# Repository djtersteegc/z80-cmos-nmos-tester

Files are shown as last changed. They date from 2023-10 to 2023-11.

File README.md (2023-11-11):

Test your Z80 CPU at multiple frequencies and detemine if your remarked chip from China is a NMOS or CMOS variant. Based  on the work originally by [Виталий Рудик](https://oshwlab.com/vitalian1980/z80-tester) and later respun/improved by [kinzi](https://www.forum64.de/index.php?thread/133402-z80-tester-zum-testen-unbekannter-z80-cpus/).

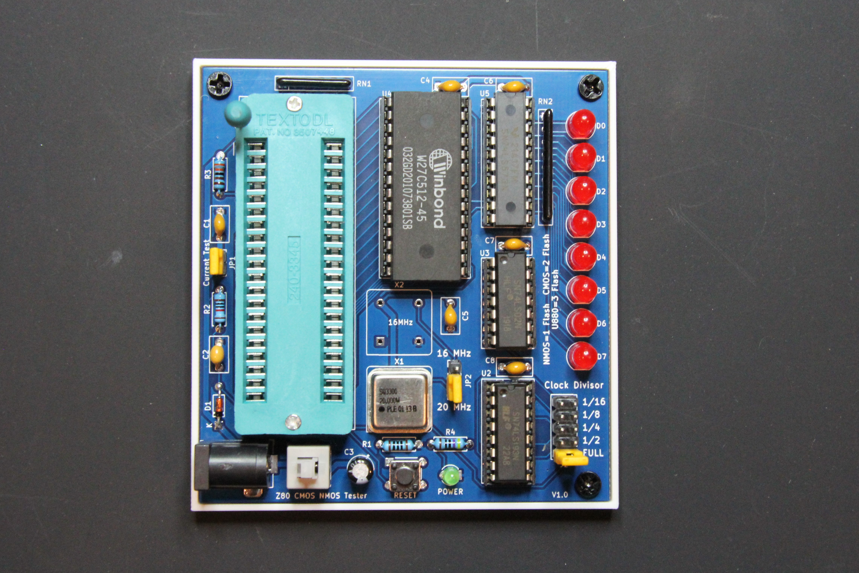
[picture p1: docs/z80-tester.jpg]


I respun the PCB again to add a few quality of life improvements I wanted like a barrel power connetor, power switch and  LED, current measuring header, improved reset circuitry, and switched to 1/2 can oscillators instead of using a crystal and associated components (Pierce oscillator).

Unlike a simple NOP tester, this one works by loading a simple program from the EPROM/EEPROM.  It first checks the variant by using undocumented instructions like `OUT (C),0` , flashes the LED array one to three times to indicate the type, and then does a LED chaser display up and down the various data bus lines. Takes up to two 1/2 can oscillators and with the frequency dividers can test at the following frequencies. 

| Divider | 20 MHz Oscillator | 16 MHz Oscillator |
| --- | --- | --- |
| Full | 20 MHz | 16 MHz |
| 1/2 | 10 MHz | 8 MHz |
| 1/4 | 5 MHz | 4 MHz |
| 1/8 | 2.5 MHz | 2 MHz |
| 1/16 | 1.25 MHz | 1 MHz |

### BOM

There is an interactive BOM [here](https://djtersteegc.github.io/z80-cmos-nmos-tester/ibom.html) or [CSV](https://djtersteegc.github.io/z80-cmos-nmos-tester/z80-cmos-nmos-tester-BOM.csv).  I like using Winbond W27C512 EEPROM's in 27C512 applications since they don't require UV to erase like a traditional EPROM.

### Assembly

In the 3D directory there are STL's to print an (optional) LED alignment jig, some support blocks to keep the board level while you solder the LED's, and a simple mounting plate. Secure the PCB to the plate with M3 x 4mm screws.

### Firmware Programming

kinzi's rev3 firmare can be found in the zip file in the **firmware** directory.  Burn **test.z80.u880.rev3.bin** to a 27C512 compatible EPROM/EEPROM.

### Usage

Supply 5V center positive to the 5.5mm x 2.1mm DC power jack. On power up, the Z80 should automatically reset, if not, push the reset button.  The LED array will flash once for NMOS variants, twice for CMOS, or three times for a U880.  After that, the LED's will go "knight rider", and then reset in a continous loop.  Use the two jumpers to select the appropiate osciallator and frequency divider you want to test at.

JP1 (Current Test) feeds 5V to the Z80. Remove the jumper and attached a multimeter in current mode if you would like to test current draw of your Z80, another way to tell NMOS and CMOS variants apart. NMOS is around 200mA, CMOS is between 10 to 100mA depending on clock frequency.

Here's a quick demo of the board in action with both a real and fake 20MHz CMOS version from a batch of ten from AliExpress, https://youtu.be/2GuPsmFTtck

https://youtu.be/2GuPsmFTtck

### Getting a PCB Board

Any extras I have available will be in my [Tindie](https://www.tindie.com/products/tersteeg/z80-cmos-nmos-tester-pcb/) store. I don't ship outside the US currently, but gerber files are available if you want to order your own from your favorite PCB fab like JLCPCB or PCBWay.

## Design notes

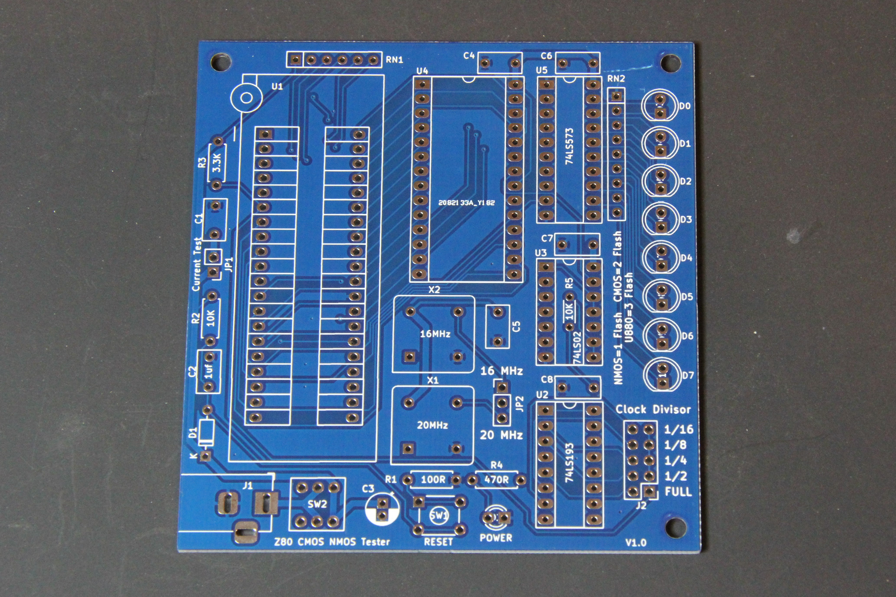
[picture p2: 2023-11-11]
docs/pcb.jpg

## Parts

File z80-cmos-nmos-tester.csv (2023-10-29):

# | Reference | Qty | Value | Footprint | DNP
1 | C1, C4, C5, C6, C7, C8 | 6 | 100nf | Capacitor_THT:C_Rect_L7.0mm_W3.5mm_P5.00mm
2 | C2 | 1 | 1uf | Capacitor_THT:C_Rect_L7.0mm_W3.5mm_P5.00mm
3 | C3 | 1 | 100uf | Capacitor_THT:CP_Radial_D5.0mm_P2.00mm
4 | D1 | 1 | BAT42 | Diode_THT:D_DO-35_SOD27_P7.62mm_Horizontal
5 | D2 | 1 | POWER | LED_THT:LED_D3.0mm
6 | D3 | 1 | D0 | LED_THT:LED_D5.0mm
7 | D4 | 1 | D1 | LED_THT:LED_D5.0mm
8 | D5 | 1 | D2 | LED_THT:LED_D5.0mm
9 | D6 | 1 | D3 | LED_THT:LED_D5.0mm
10 | D7 | 1 | D4 | LED_THT:LED_D5.0mm
11 | D8 | 1 | D5 | LED_THT:LED_D5.0mm
12 | D9 | 1 | D6 | LED_THT:LED_D5.0mm
13 | D10 | 1 | D7 | LED_THT:LED_D5.0mm
14 | H1, H2, H3 | 3 | MountingHole | MountingHole:MountingHole_3.2mm_M3
15 | J1 | 1 | Barrel_Jack | Connector_BarrelJack:BarrelJack_Horizontal
16 | J2 | 1 | Conn_02x05_Odd_Even | Connector_PinHeader_2.54mm:PinHeader_2x05_P2.54mm_Vertical
17 | JP1 | 1 | Current Test | Connector_PinHeader_2.54mm:PinHeader_1x02_P2.54mm_Vertical
18 | JP2 | 1 | 16MHz/20MHz | Connector_PinHeader_2.54mm:PinHeader_1x03_P2.54mm_Vertical
19 | R1 | 1 | 100R | Resistor_THT:R_Axial_DIN0207_L6.3mm_D2.5mm_P7.62mm_Horizontal
20 | R2 | 1 | 10K | Resistor_THT:R_Axial_DIN0207_L6.3mm_D2.5mm_P7.62mm_Horizontal
21 | R3 | 1 | 3.3K | Resistor_THT:R_Axial_DIN0207_L6.3mm_D2.5mm_P7.62mm_Horizontal
22 | R4 | 1 | 470R | Resistor_THT:R_Axial_DIN0207_L6.3mm_D2.5mm_P7.62mm_Horizontal
23 | R5 | 1 | 10K | Resistor_THT:R_Axial_DIN0204_L3.6mm_D1.6mm_P5.08mm_Horizontal
24 | RN1 | 1 | 4.7K | Resistor_THT:R_Array_SIP6
25 | RN2 | 1 | 1K | Resistor_THT:R_Array_SIP9
26 | SW1 | 1 | RESET | Button_Switch_THT:SW_TH_Tactile_Omron_B3F-10xx
27 | SW2 | 1 | SW_DPDT_x2 | Tersteeg:KFC8.5x8.5 DPDT Push Switch
28 | U1 | 1 | Z80CPU | Socket:3M_Textool_240-1288-00-0602J_2x20_P2.54mm
29 | U2 | 1 | 74LS193 | Package_DIP:DIP-16_W7.62mm_Socket_LongPads
30 | U3 | 1 | 74LS02 | Package_DIP:DIP-14_W7.62mm_Socket_LongPads
31 | U4 | 1 | 27C512 | Package_DIP:DIP-28_W15.24mm_Socket_LongPads
32 | U5 | 1 | 74LS573 | Package_DIP:DIP-20_W7.62mm_Socket_LongPads
33 | X1 | 1 | 20MHz | Oscillator:Oscillator_DIP-8
34 | X2 | 1 | 16MHz | Oscillator:Oscillator_DIP-8

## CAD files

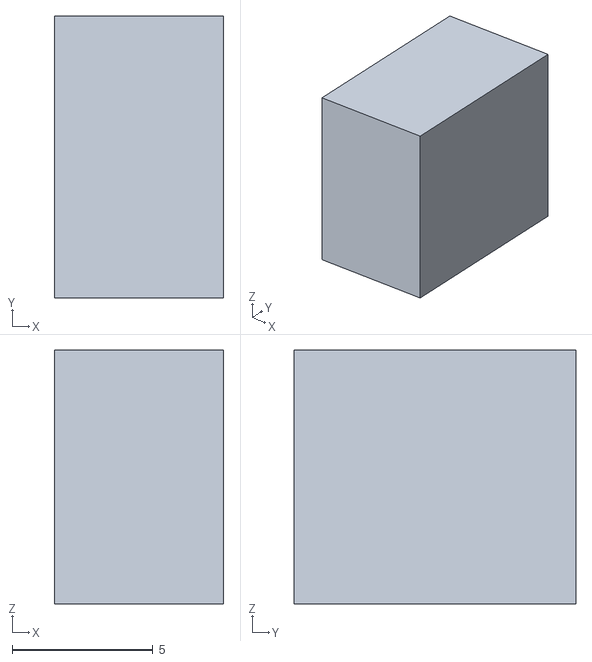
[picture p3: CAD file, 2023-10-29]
3D/LED Alignment Jig Corner Support.stl
6.00 x 10.0 x 9.00

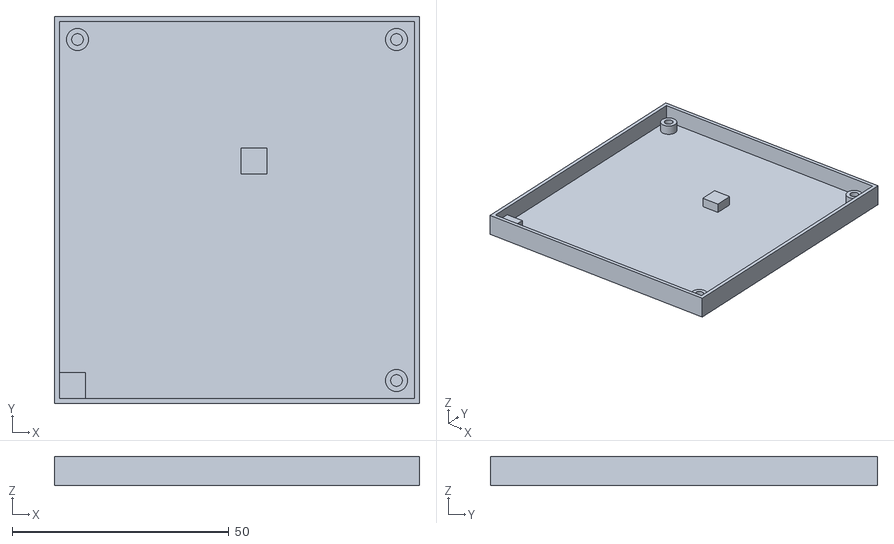
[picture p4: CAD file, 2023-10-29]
3D/z80-cmos-nmos-tester.stl
84.3 x 89.4 x 6.80

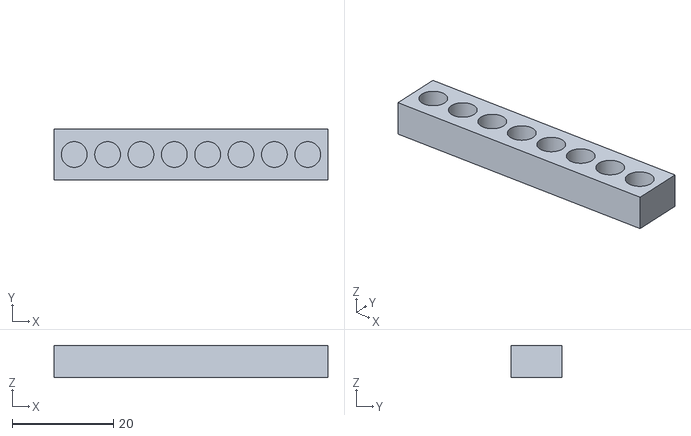
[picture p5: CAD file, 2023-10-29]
3D/LED Alignment Jig.stl
54.2 x 10.0 x 6.40

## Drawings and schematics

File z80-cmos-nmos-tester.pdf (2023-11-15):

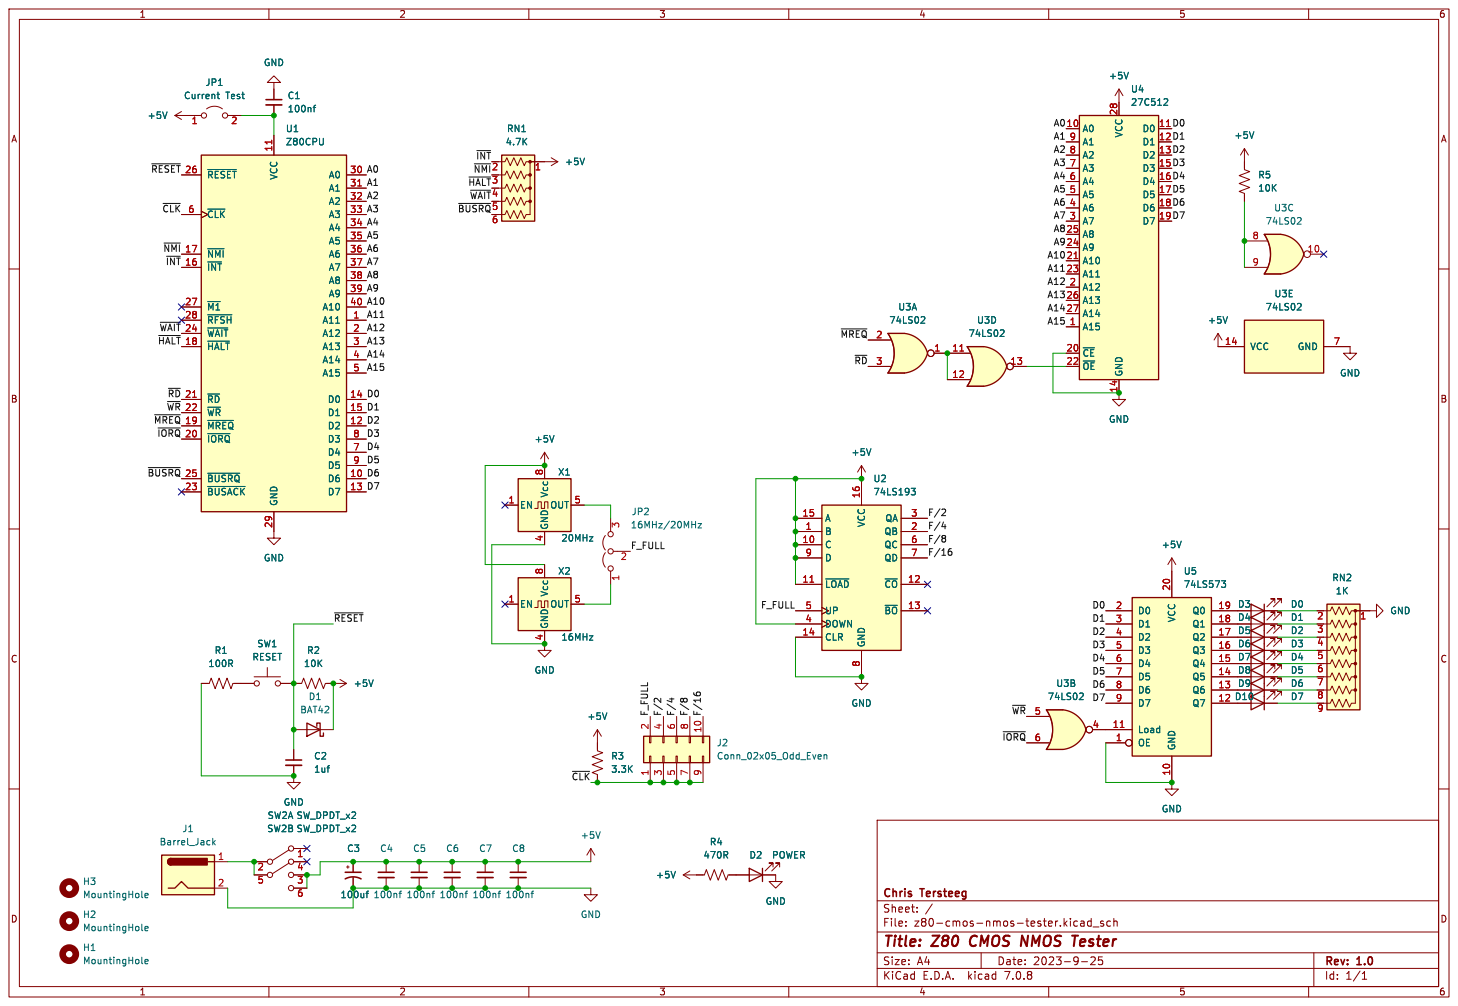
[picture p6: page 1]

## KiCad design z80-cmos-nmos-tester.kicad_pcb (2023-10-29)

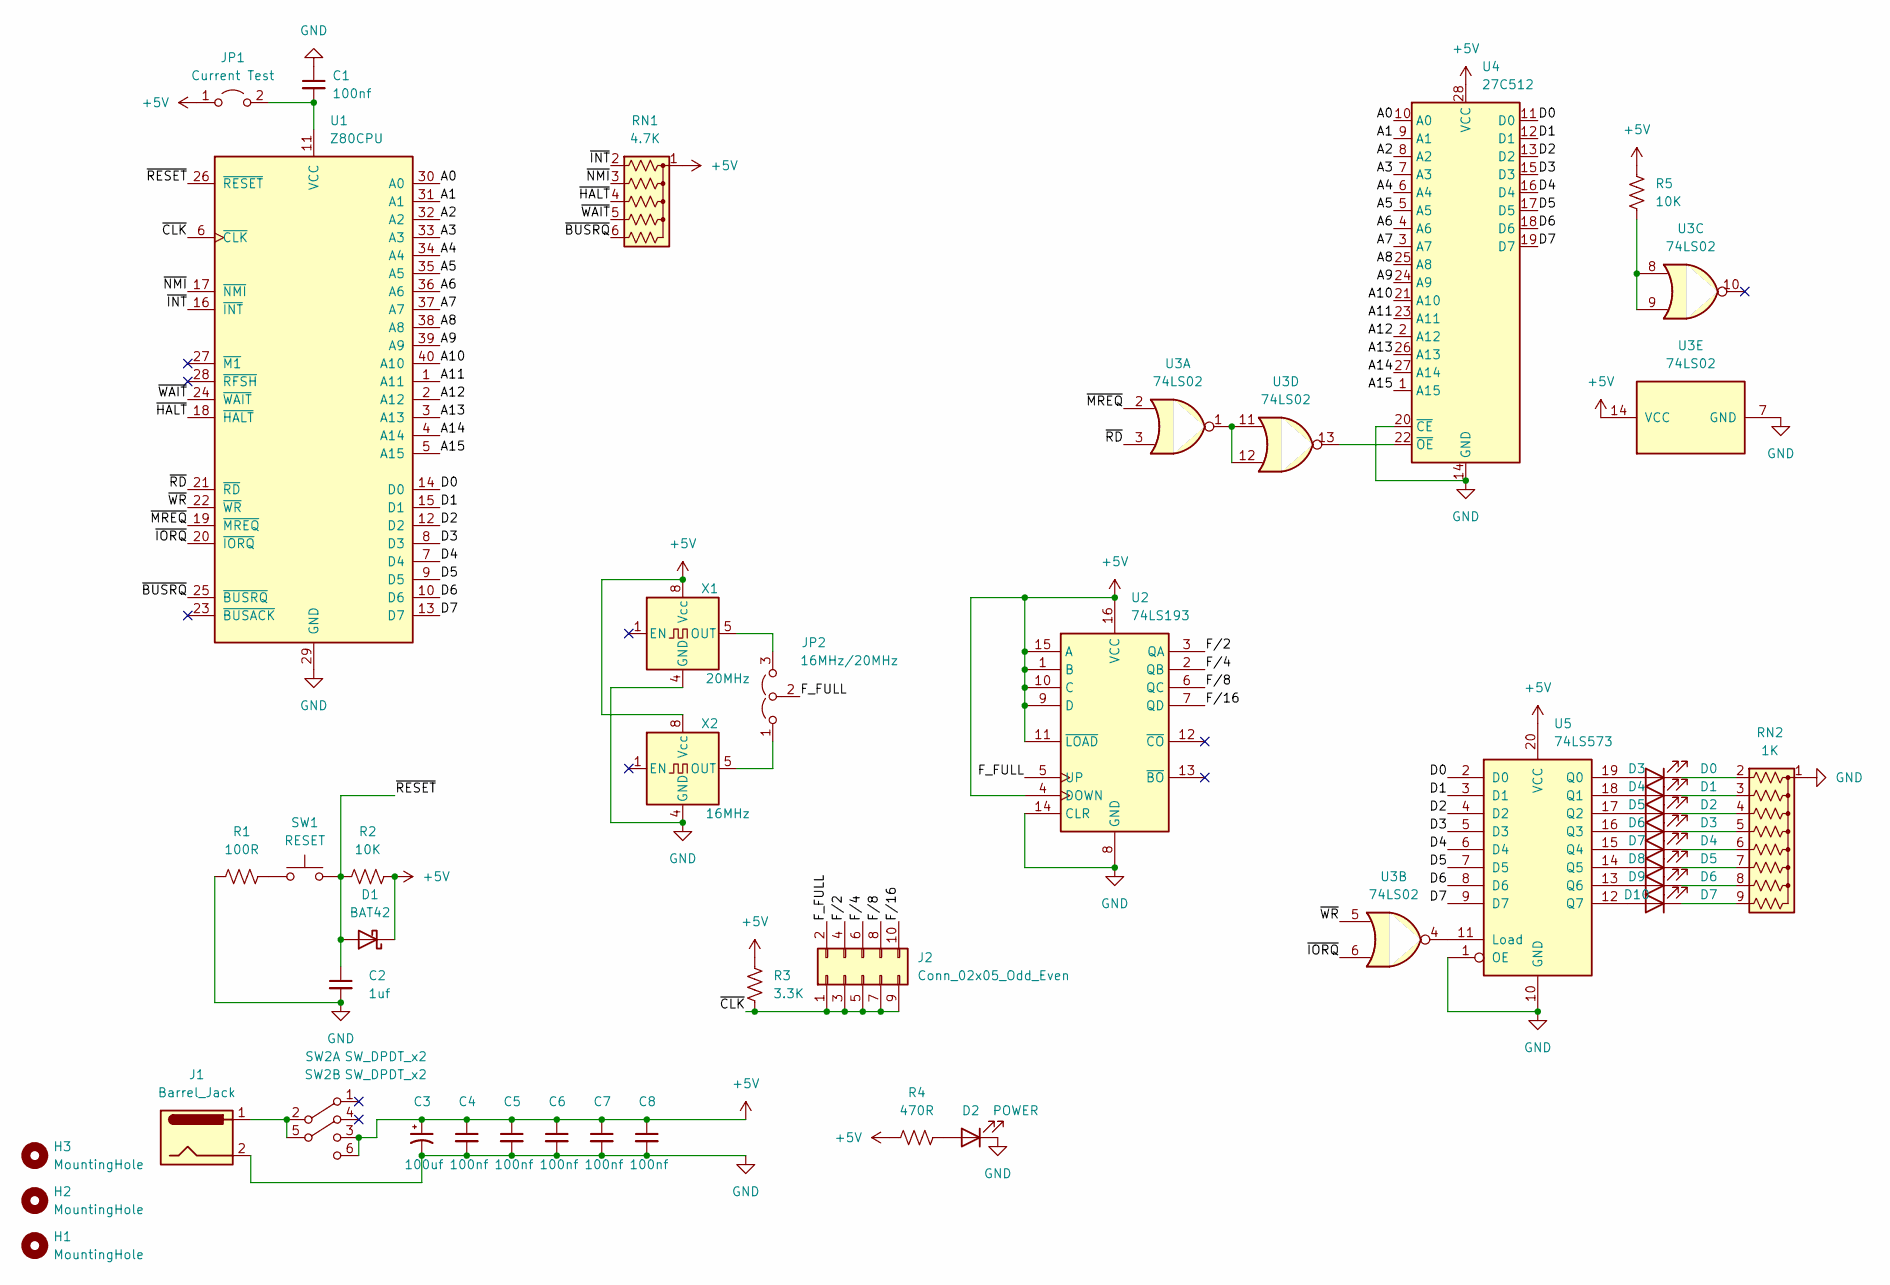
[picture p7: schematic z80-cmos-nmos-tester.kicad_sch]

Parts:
C1, C4, C5, C6, C7, C8: 100nf; C_Rect_L7.0mm_W3.5mm_P5.00mm
C2: 1uf; C_Rect_L7.0mm_W3.5mm_P5.00mm
C3: 100uf; CP_Radial_D5.0mm_P2.00mm
D1: BAT42; D_DO-35_SOD27_P7.62mm_Horizontal
D2: POWER; LED_D3.0mm
D3: D0; LED_D5.0mm
D4: D1; LED_D5.0mm
D5: D2; LED_D5.0mm
D6: D3; LED_D5.0mm
D7: D4; LED_D5.0mm
D8: D5; LED_D5.0mm
D9: D6; LED_D5.0mm
D10: D7; LED_D5.0mm
H1, H2, H3: MountingHole; MountingHole_3.2mm_M3
J1: Barrel_Jack; BarrelJack_Horizontal
J2: Conn_02x05_Odd_Even; PinHeader_2x05_P2.54mm_Vertical
JP1: Current Test; PinHeader_1x02_P2.54mm_Vertical
JP2: 16MHz/20MHz; PinHeader_1x03_P2.54mm_Vertical
R1: 100R; R_Axial_DIN0207_L6.3mm_D2.5mm_P7.62mm_Horizontal
R2: 10K; R_Axial_DIN0207_L6.3mm_D2.5mm_P7.62mm_Horizontal
R3: 3.3K; R_Axial_DIN0207_L6.3mm_D2.5mm_P7.62mm_Horizontal
R4: 470R; R_Axial_DIN0207_L6.3mm_D2.5mm_P7.62mm_Horizontal
R5: 10K; R_Axial_DIN0204_L3.6mm_D1.6mm_P5.08mm_Horizontal
RN1: 4.7K; R_Array_SIP6
RN2: 1K; R_Array_SIP9
SW1: RESET; SW_TH_Tactile_Omron_B3F-10xx
SW2: SW_DPDT_x2; KFC8.5x8.5 DPDT Push Switch
U1: Z80CPU; 3M_Textool_240-1288-00-0602J_2x20_P2.54mm
U2: 74LS193; DIP-16_W7.62mm_Socket_LongPads
U3: 74LS02; DIP-14_W7.62mm_Socket_LongPads
U4: 27C512; DIP-28_W15.24mm_Socket_LongPads
U5: 74LS573; DIP-20_W7.62mm_Socket_LongPads
X1: 20MHz; Oscillator_DIP-8
X2: 16MHz; Oscillator_DIP-8

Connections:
+5V: C3.1, C4.1, C5.1, C6.1, C7.1, C8.1, D1.1 (K), JP1.1 (A), R2.2, R3.2, R4.2, R5.2, RN1.1 (common), SW2.3 (C), SW2.6 (C), U2.1 (B), U2.4 (DOWN), U2.9 (D), U2.10 (C), U2.11 (~LOAD), U2.15 (A), U2.16 (VCC), U3.14 (VCC), U4.28 (VCC), U5.20 (VCC), X1.8 (Vcc), X2.8 (Vcc)
/A0: U1.30 (A0), U4.10 (A0)
/A1: U1.31 (A1), U4.9 (A1)
/A2: U1.32 (A2), U4.8 (A2)
/A3: U1.33 (A3), U4.7 (A3)
/A4: U1.34 (A4), U4.6 (A4)
/A5: U1.35 (A5), U4.5 (A5)
/A6: U1.36 (A6), U4.4 (A6)
/A7: U1.37 (A7), U4.3 (A7)
/A8: U1.38 (A8), U4.25 (A8)
/A9: U1.39 (A9), U4.24 (A9)
/A10: U1.40 (A10), U4.21 (A10)
/A11: U1.1 (A11), U4.23 (A11)
/A12: U1.2 (A12), U4.2 (A12)
/A13: U1.3 (A13), U4.26 (A13)
/A14: U1.4 (A14), U4.27 (A14)
/A15: U1.5 (A15), U4.1 (A15)
/D0: U1.14 (D0), U4.11 (D0), U5.2 (D0)
/D1: U1.15 (D1), U4.12 (D1), U5.3 (D1)
/D2: U1.12 (D2), U4.13 (D2), U5.4 (D2)
/D3: U1.8 (D3), U4.15 (D3), U5.5 (D3)
/D4: U1.7 (D4), U4.16 (D4), U5.6 (D4)
/D5: U1.9 (D5), U4.17 (D5), U5.7 (D5)
/D6: U1.10 (D6), U4.18 (D6), U5.8 (D6)
/D7: U1.13 (D7), U4.19 (D7), U5.9 (D7)
/F_FULL: J2.2, JP2.2 (C), U2.5 (UP)
/F/2: J2.4, U2.3 (QA)
/F/4: J2.6, U2.2 (QB)
/F/8: J2.8, U2.6 (QC)
/F/16: J2.10, U2.7 (QD)
/~BUSRQ: RN1.6 (R5), U1.25 (~BUSRQ)
/~CLK: J2.1, J2.3, J2.5, J2.7, J2.9, R3.1, U1.6 (~CLK)
/~HALT: RN1.4 (R3), U1.18 (~HALT)
/~INT: RN1.2 (R1), U1.16 (~INT)
/~IORQ: U1.20 (~IORQ), U3.6
/~MREQ: U1.19 (~MREQ), U3.2
/~NMI: RN1.3 (R2), U1.17 (~NMI)
/~RD: U1.21 (~RD), U3.3
/~RESET: C2.1, D1.2 (A), R2.1, SW1.2, U1.26 (~RESET)
/~WAIT: RN1.5 (R4), U1.24 (~WAIT)
/~WR: U1.22 (~WR), U3.5
GND: C1.1, C2.2, C3.2, C4.2, C5.2, C6.2, C7.2, C8.2, D2.1 (K), J1.2, R1.1, RN2.1 (common), U1.29 (GND), U2.8 (GND), U2.14 (CLR), U3.7 (GND), U4.14 (GND), U4.20 (~CE), U5.1 (OE), U5.10 (GND), X1.4 (GND), X2.4 (GND)
unnamed: D2.2 (A), R4.1
unnamed: D3.2 (A), U5.19 (Q0)
unnamed: D3.1 (K), RN2.2 (R1)
unnamed: D4.2 (A), U5.18 (Q1)
unnamed: D4.1 (K), RN2.3 (R2)
unnamed: D5.2 (A), U5.17 (Q2)
unnamed: D5.1 (K), RN2.4 (R3)
unnamed: D6.2 (A), U5.16 (Q3)
unnamed: D6.1 (K), RN2.5 (R4)
unnamed: D7.2 (A), U5.15 (Q4)
unnamed: D7.1 (K), RN2.6 (R5)
unnamed: D8.2 (A), U5.14 (Q5)
unnamed: D8.1 (K), RN2.7 (R6)
unnamed: D9.2 (A), U5.13 (Q6)
unnamed: D9.1 (K), RN2.8 (R7)
unnamed: D10.2 (A), U5.12 (Q7)
unnamed: D10.1 (K), RN2.9 (R8)
unnamed: C1.2, JP1.2 (B), U1.11 (VCC)
unnamed: JP2.1 (A), X2.5 (OUT)
unnamed: JP2.3 (B), X1.5 (OUT)
unnamed: R1.2, SW1.1
unnamed: R5.1, U3.8, U3.9
unnamed: J1.1, SW2.2 (B), SW2.5 (B)
unnamed: U3.1, U3.11, U3.12
unnamed: U3.13, U4.22 (~OE)
unnamed: U3.4, U5.11 (Load)

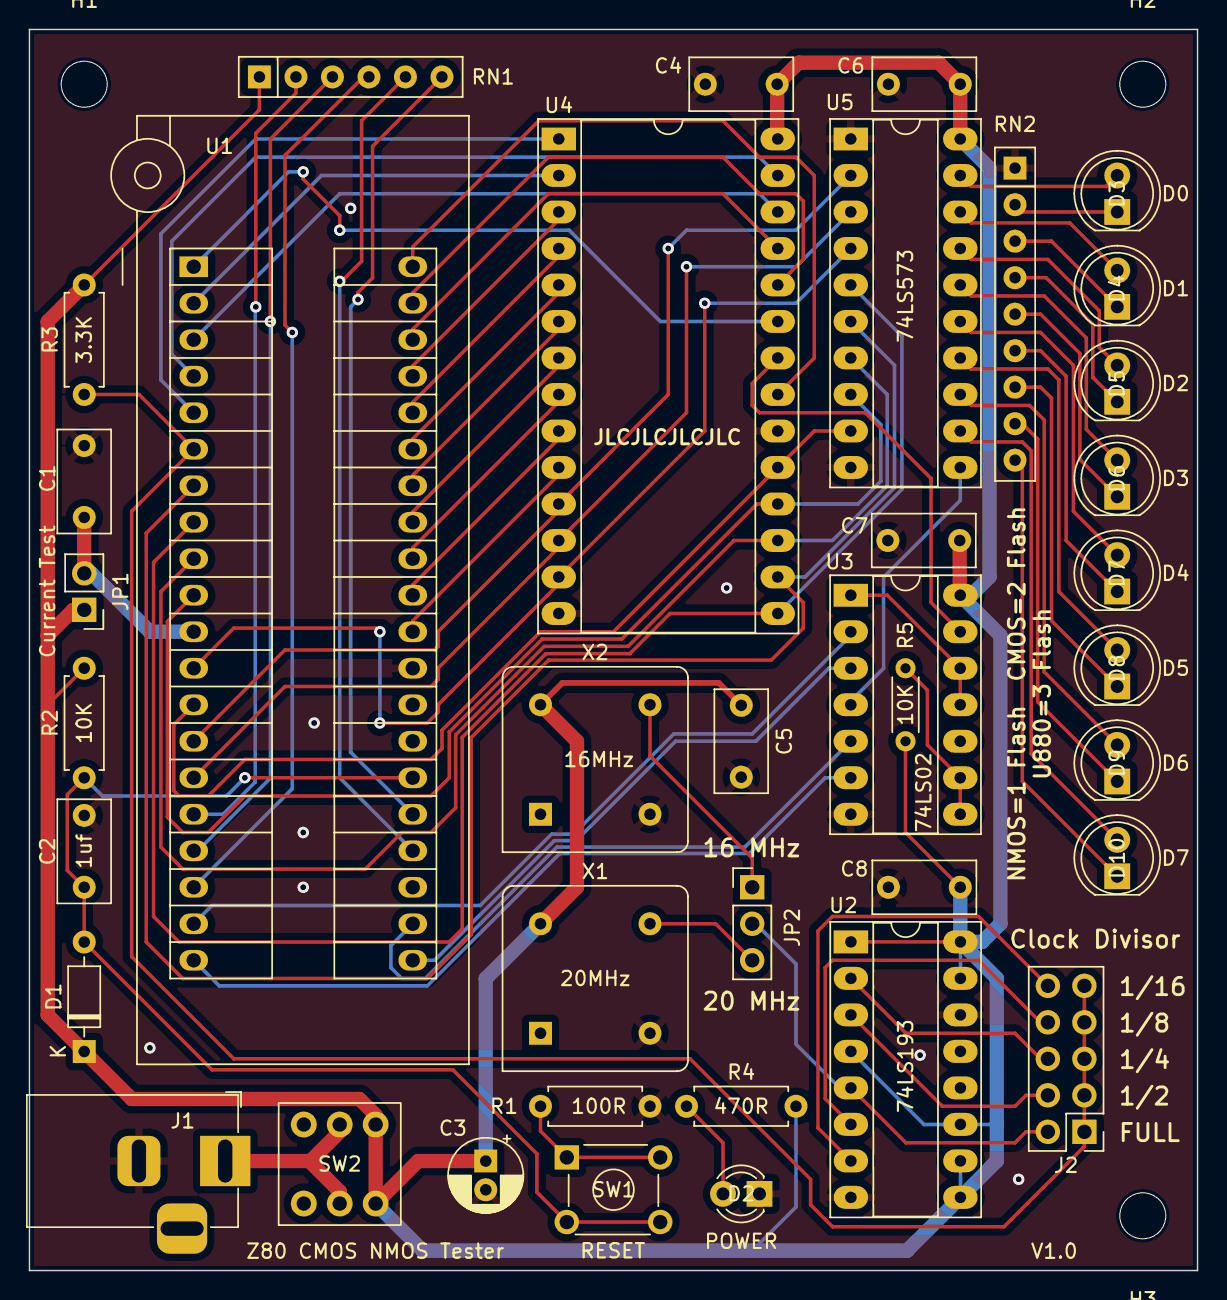
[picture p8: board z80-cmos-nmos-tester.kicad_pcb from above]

Board: 2 copper layers, 81.3 x 86.4 mm, 41 parts (0 on the bottom side), 68 nets.

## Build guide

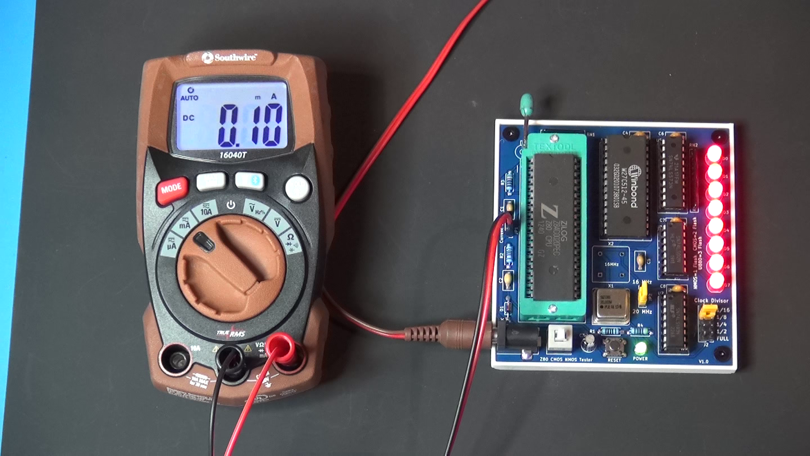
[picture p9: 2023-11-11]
docs/usage.png

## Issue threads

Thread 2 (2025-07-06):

M1 indication

rabs664, 2025-07-06:
Not an issue as such more an enhancement. Nice little project by the way.

Would be nice if it had an M1 activity LED. Some of the Z80s installed in ZX Spectrums had no M1 activity. Not an issue for the ZX Spectrum until you use an expansion that senses M1.

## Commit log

2023-10-29 Initial version
    [LED Alignment Jig Corner Support.stl, LED Alignment Jig.stl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]
2023-10-29 Add CSV BOM
    [z80-cmos-nmos-tester-BOM.csv]
2023-11-15 Add CSV BOM and PDF schematic
    [z80-cmos-nmos-tester.csv, z80-cmos-nmos-tester.kicad_sch]
